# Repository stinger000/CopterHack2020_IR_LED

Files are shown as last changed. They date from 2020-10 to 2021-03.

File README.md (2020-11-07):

# CopterHack2020_IR_LED
The main repository of the team "Atomic Ferrets" in the competition CopterHack 2020

## Описание проекта

- Проект представляет собой систему инфракрасной засечки, которая устанавливается на ворота или любое другое препятствие на трассе, и позволяет фиксировать факт пролёта дроном определенного элемента трассы, а также засекать время пролёта. Данная система позволит максимально автоматизировать проведение любых соревнований, связанных с беспилотным спортом. Так, участнику будет достаточно просто запустить дрон, после чего вылет будет оценен автоматически, в соответствии с заданными критериями. Это позволит исключить возможность судейской ошибки и позволит оценивать проведение любых чемпионатов максимально объективно.

## Каким мы видим результат проекта?

- Проект будет представлен в виде системы инфракрасных датчиков, которые крепятся к препятствиям трассы, а также базовой станции, которая принимает и обрабатывает сигнал с этих датчиков. Датчики могут подключаться последовательно, что позволит устанавливать их на элементы трассы любого размера. В базовых станциях будет реализована возможность их объединения в единую сеть посредствам беспроводного интерфейса, что позволит засекать прохождение любого количества элементов трассы. Также, в рамках проекта будет реализовано приложение для мобильного телефона и ПК, которое будет принимать сигнал с базовых станций, позволит задавать конфигурацию трассы, критерии оценки, и по окончанию вылета выдавать оценку в автоматическом режиме.

## Клевер

- Клевер сейчас является одной из самых популярных платформ для проведения беспилотных соревнований. Разрабатывая нашу систему засечки мы в первую очередь ориентируемся на соревнования с участием этого дрона. Хотя стоит сказать, что использовать устройство можно на любых других соревнованиях. Также ее может использовать любой желающий подготовиться к соревнованиям либо в других личных целях. Конечный вид сборки устройства и установки софта предполагает простоту в использовании

## Место продукта на рынке

- Наша версия системы засечки предполагает, что на дрон не придется ставить дополнительное оборудование, которое будет увеличивать его вес ( максимум - это один светодиод, который позволит определять какой имеено дрон пролетает. Этот вариант еще не реализован ). Многие системы засечек предлагают При этом полный комплект оборудования с реализованным на нём ПО предполагает невысокую стоимость. Конечного продукта нет, поэтому и точной цены тоже, но мы хотим сделать продукт доступным в цене, и опираемся на эту идею при разработке. 

## Стадия разработки
- **Видео** с проверкой работоспособности проекта можете посмотреть по ссылке https://youtu.be/BEOIffvngIY
- Засечка осуществляется за счет фотодиода, реагирующего на свет. Измерения осуществляются путем срабатывания системы на светодиод, закрепленный на противоположной стороне ворот соосно системе срабатывания. 
- Сейчас у нас есть электронная схема, позволяющая снять данные с фотодиода для последующей ее обработки. 
 
- Разработана электронная схема для засечки. 
- Создан алгоритм обработки сигнала с засечки
- Создается софт для ПК с интерфейсом наблюдения замеров времени. https://github.com/stinger000/CopterHack2020_IR_LED_Desktop_GUI
- Была реализована тестовая модель засечки, на которой было проверено срабатывание системы на светодиод, и она оказалась рабочей. 
- Есть система передачи видео с дрона через интернет в любую точку планеты
- Идёт процесс создания мобильного приложения для отслеживания замеров
 
 ### Дальнейшие планы 
- разработать приложение для конечного пользователя на PC и Android
- создать корпус для системы, позволяющий ей правильно работать в полевых условиях (закреплен на препятствие и правильно реагирует на пролет дрона) 

   Возможно рассмотрение некоторых вариантов реализации 
- **Идентификация дронов по частоте мигания светодиода**. Если на квадракоптеры установить по одному светодиоду, и сделать так, чтобы они мигали с индивидуальной для каждого  дрона частотой, то таким образом можно попытаться различить, кто и когда пролетел через препятствие, анализируя полученные сигналы.
- **Идентификация дронов с помощью камер и меток.** В интернете реализован проект система засечки, использующий только камеры самих дронов и передатчики видео. В этом проекте на контрольных точках устанавливается множество aruco-меток, с помощью которых фиксирует время прохождения этих точек. Мы хотим использовать этот проект, таким образом объединив 2 решения. Нашу систему, которая точно определяет время каждого пролета, но пока не может определить кто их соверишл. И систему, которая с неизвестной точностью, но определяет время пролета и id гонщика.

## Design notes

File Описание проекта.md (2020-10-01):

## Описание проекта

- Проект представляет собой систему инфракрасной засечки, которая устанавливается на ворота или любое другое препятствие на трассе, и позволяют фиксировать факт пролёта определенного объекта дроном, а также засекать время пролёта. Данная система позволит максимально автоматизировать проведение любых соревнований, связанных с беспилотным спортом. Так, участнику будет достаточно просто запустить дрон, после чего вылет будет оценен автоматически, в соответствии с заданными критериями. Это позволит исключить возможность судейской ошибки и позволит оценивать проведение любых чемпионатов максимально объективно.

## Каким мы видим результат проекта?

- Проект будет представлен в виде системы инфракрасных датчиков, которые крепятся к препятствиям трассы, а также базовой станции, которая принимает и обрабатывает сигнал с этих датчиков. Датчики могут подключаться последовательно, что позволит устанавливать их на элементы трассы любого размера. В базовых станциях будет реализована возможность их объединения в единую сеть посредствам беспроводного интерфейса, что позволит засекать прохождение любого количества элементов трассы. Также, в рамках проекта будет реализовано приложение для мобильного телефона и ПК, которое будет принимать сигнал с базовых станций, позволит задавать конфигурацию трассы, критерии оценки, и по окончанию вылета выдавать оценку в автоматическом режиме.

## Клевер

- Клевер сейчас является одной из самых популярных платформ для проведения беспилотных соревнований. Таким образом, разрабатывая нашу систему засечки мы в первую очередь ориентируемся на соревнования с участием этого дрона. Хотя стоит сказать, что использовать устройство можно на любых других соревнованиях. Также ее может использовать любой желающий подготовиться к соревнованиям либо в других личных целях. Конечный вид сборки устройства и установки софта предполагает простоту в использовании

## Стадия разработки

- Засечка осуществляется за счет фотодиода, реагирующего на свет. Измерения осуществляются путем срабатывания системы на светодиод, закрепленный на противоположной стороне ворот соосно системе срабатывания. 
- Сейчас у нас есть электронная схема, позволяющая снять данные с фотодиода для последующей ее обработки. 

 - На данный момент 
1) Разработана электронная схема для засечки. 
2) Создан алгоритм обработки сигнала с засечки
3) Создан софт для отслеживания замеров на ПК
4) Была реализована тестовая модель засечки, на которой было проверено срабатывание системы на светодиод, и она оказалась рабочей. 
5) Есть система передачи видео с дрона через интернет в любую точку планеты
6) Идёт процесс создания мобильного приложения для отслеживания замеров
 В дальнейшем планируется : 
 - разработать приложение для конечного пользователя на PC и Android
 - создать корпус для системы, позволяющий ей правильно работать в полевых условиях (закреплен на препятствие и правильно реагирует на пролет дрона)

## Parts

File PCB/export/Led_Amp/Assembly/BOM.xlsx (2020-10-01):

Item # | *Ref Des | *Qty | Manufacturer | *Mfg Part # | Description / Value | *Package | Type | Your Instructions / Notes
1 | U1 | 1 | Analog Devices |  | AD8605ARTZ-R2 | SOT-23-5 | SMD
2 | PH1 | 1 | Betlux Electronics |  | BL-L3522PD | 3mm*5.1mm | thru-hole
3 | R1, R2 | 2 |  |  | RES 2.4M OHM 1/8W 1% 0805 SMD | 0805 | SMD
4 | R3, R4 | 2 |  |  | RES 10k OHM 1/8W 1% 0805 SMD | 0805 | SMD
5 | C1, C2 | 1 |  |  | CAP CER 2.2UF 16V X7R 0805 | 0805 | SMD
Contacts:
bigbani1334@gmail.com
Sergey Stetsky

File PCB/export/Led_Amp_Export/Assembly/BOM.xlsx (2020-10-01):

Item # | *Ref Des | *Qty | Manufacturer | Description / Value | *Package | Type | Your Instructions / Notes
1 | U1 | 1 | Analog Devices | AD8605ARTZ-R2 | SOT-23-5 | SMD
2 | PH1 | 1 | Betlux Electronics | BL-L3522PD | 3mm*5.1mm | thru-hole
3 | R1, R2 | 2 |  | RES 2.4M OHM 1/8W 1% 0805 SMD | 0805 | SMD
4 | R3, R4 | 2 |  | RES 10k OHM 1/8W 1% 0805 SMD | 0805 | SMD
5 | C1, C2 | 2 |  | CAP CER 2.2UF 16V X7R 0805 | 0805 | SMD
6 | JP1, JP2 | 2 | JST | B8B-XH-A |  | thru-hole
Contacts:
bigbani1334@gmail.com
Sergey Stetsky

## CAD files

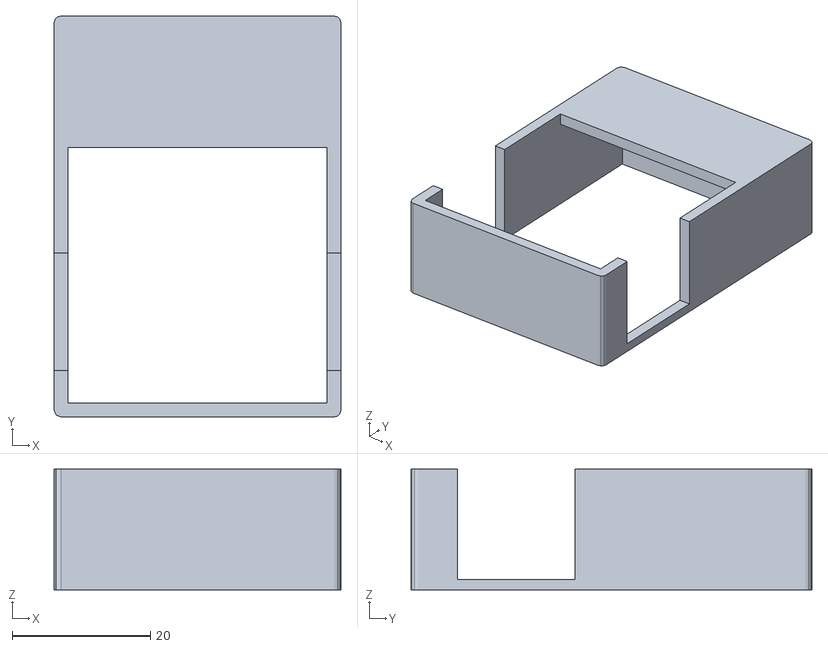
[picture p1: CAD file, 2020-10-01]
models/Body_details/top_cap.stl
41.5 x 58.0 x 17.5

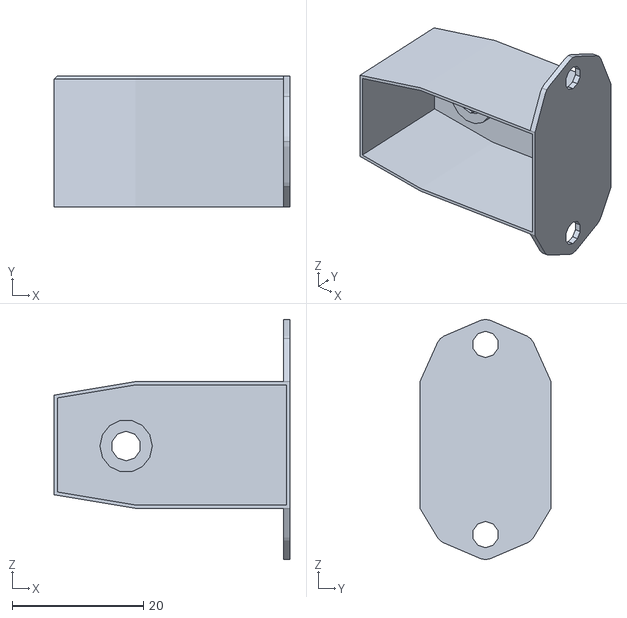
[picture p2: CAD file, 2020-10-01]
models/led_body/креп_свет.stl
36.0 x 20.0 x 36.6

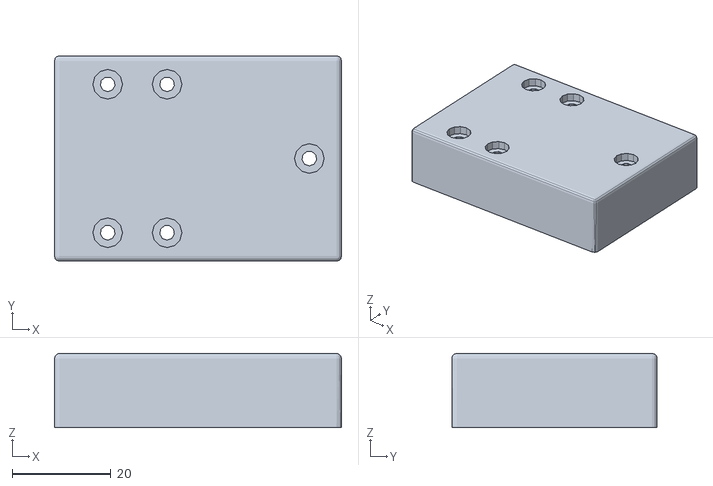
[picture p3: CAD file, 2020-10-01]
models/Body_details/bottom_part.stl
58.0 x 41.5 x 15.0

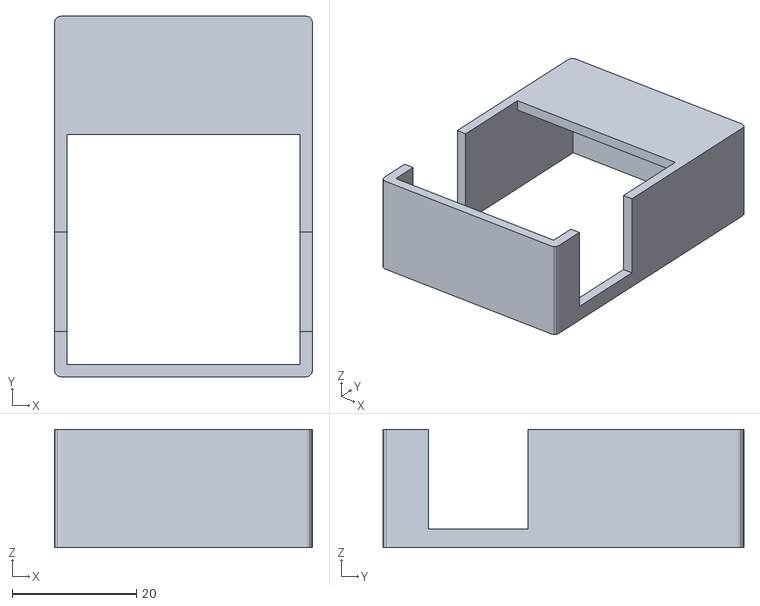
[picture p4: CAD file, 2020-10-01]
models/Body_details/top_part.stl
41.5 x 58.0 x 19.0

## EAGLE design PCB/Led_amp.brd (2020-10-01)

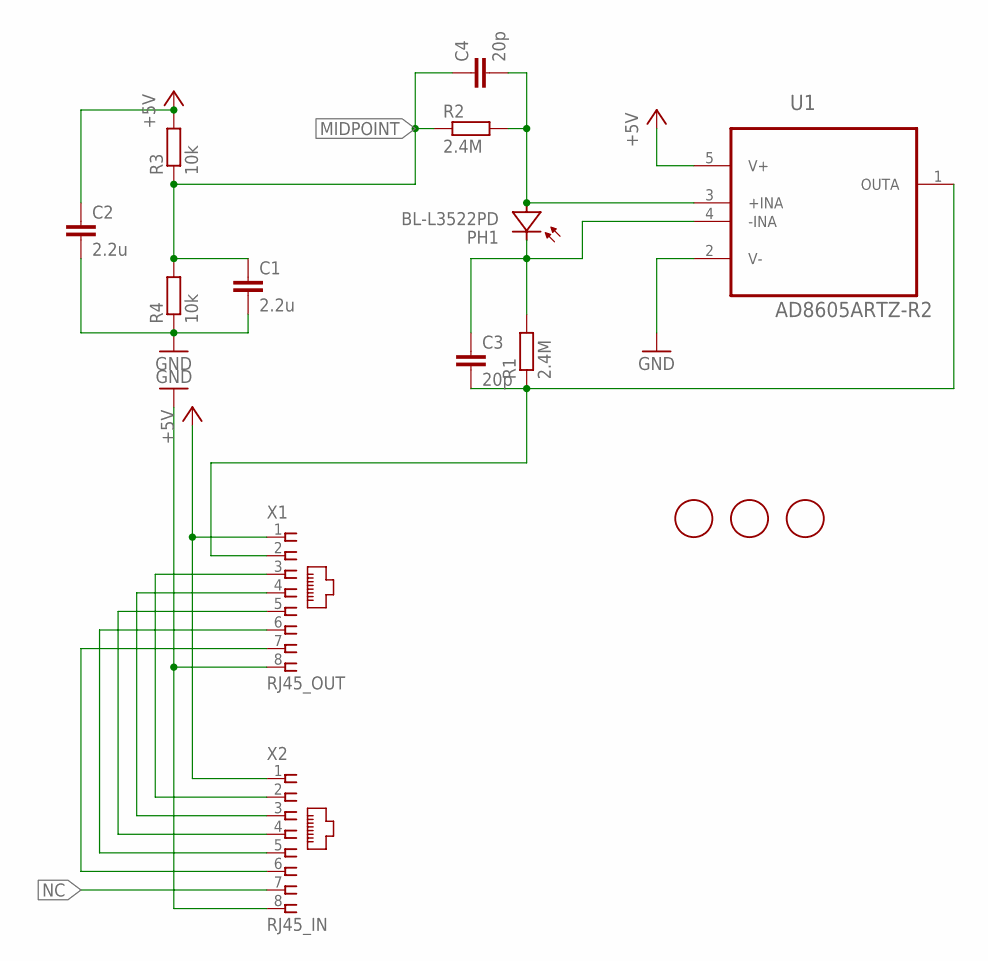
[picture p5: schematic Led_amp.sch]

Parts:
C1, C2: 2.2u; C0805
C3, C4: 20p; C0805
PH1: BL-L3522PD; PDOTODIODE_RECT
R1, R2: 2.4M; R0805
R3, R4: 10k; R0805
U1: AD8605ARTZ-R2; SOT95P290X145-5N
U$1, U$2, U$3: FIDUCIALLARGE_1MM; FIDUCIAL_1MM_LARGE
X1: RJ45_OUT; DS1134
X2: RJ45_IN; DS1134

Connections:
+5V: C2.1, R3.2, U1.5 (V+), X1.1, X2.1
GND: C1.2, C2.2, R4.1, U1.2 (V-), X1.8, X2.8
IN+: C4.2, PH1.A, R2.2, U1.3 (+INA)
IN-: C3.1, PH1.K (C), R1.2, U1.4 (-INA)
MIDPOINT: C1.1, C4.1, R2.1, R3.1, R4.2
NC: X2.7
OUT: C3.2, R1.1, U1.1 (OUTA), X1.2
OUT2: X1.3, X2.2
OUT3: X1.4, X2.3
OUT4: X1.5, X2.4
OUT5: X1.6, X2.5
OUT6: X1.7, X2.6

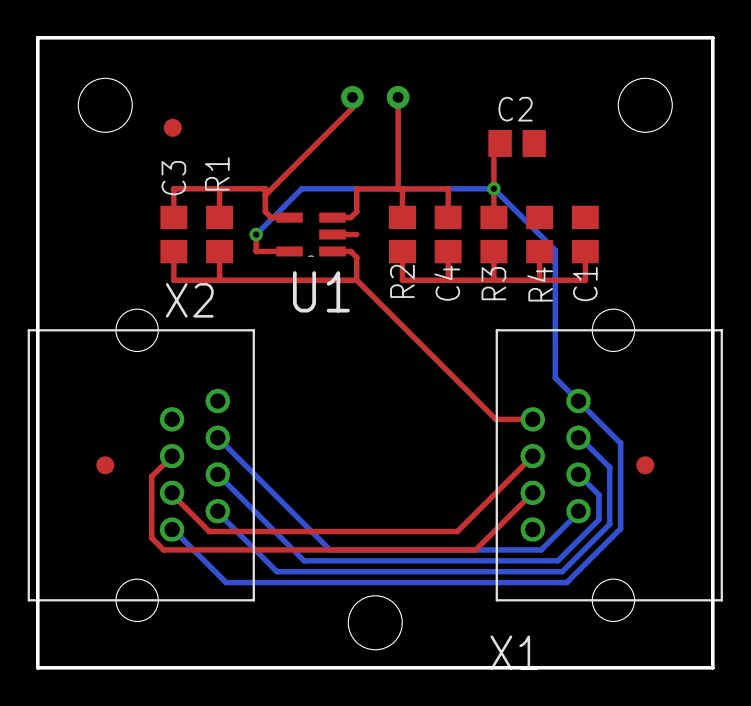
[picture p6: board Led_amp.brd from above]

Board: 2 copper layers, 37.5 x 35.0 mm, 15 parts (1 on the bottom side), 11 nets.

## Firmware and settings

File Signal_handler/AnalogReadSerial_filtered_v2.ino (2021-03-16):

#include <math.h>

const int led_pin=11;
const int sig_pin = A0;

double value = 0.0;
const double gain = 0.25;
double prev = 0.0;
const unsigned long relax_time = 500;
const double treshold = -10;
unsigned long last_time = 0;

const unsigned int interval = 10.;
const unsigned int wait_time = 20;
double Amin = 100000.0;
double Amax = -100000.0;
double tmax, tmin, t_rising, t_falling;
bool rising_edge, falling_edge;
double integral = 0.0;
double d_value;
bool detect = false;

double R = 43.0; // Resistor in low-pass-filter in ligth-emittin diod
double tau = 10.;

double t, t1, t2;
double sensorValue;

const int calib_size = 100; // Calibration time
double noise = 0.0;

const double devider = 0.0033;

double median = 1.;

// the setup routine runs once when you press reset:
void setup() {
    // initialize serial communication at 9600 bits per second:
    Serial.begin(115200);
    Serial.flush();
    //Serial.println("VAL, DET, RIS, FALL"); // for debug 3rd algorith
    //Serial.println("SensVal, Val, SrcSig");
    pinMode(2, OUTPUT);
    pinMode(led_pin, OUTPUT);
  
    //// Calibration
    double calib_arr[2][calib_size];
    double sensorValue;
    double STD_2 = 0.0;
    double mean = 0.0;
    for (int i=0; i<calib_size; i++)
    {
      sensorValue = analogRead(sig_pin)/100.0;
      calib_arr[0][i] = millis();
      delay(interval);
      calib_arr[1][i] = sensorValue;
      mean += sensorValue;
      
      /*
      Serial.print(i);
      Serial.print(" ,");
      Serial.println(sensorValue);
      */
    }
    mean /= (double)calib_size;
    //Serial.print("mean is ");
    //Serial.println(mean);
    for (int i=0; i<calib_size; i++)
    {
      //Accumulate squared deviation from meaт
      STD_2 += (calib_arr[1][i] - mean)*(calib_arr[1][i] - mean);
      //Serial.println(STD_2);
    }
    //Serial.println(STD_2);
    STD_2 /= (double)(calib_size-1);
    //Serial.println(STD_2);
    STD_2 = sqrt(STD_2);
    //Serial.println(STD_2);
    //STD_2 /= (double)sqrt(calib_size);
    noise = STD_2*100.0;
    //Serial.print("The noise size is ");
    //Serial.println(noise);
    //// Noise is STD = sqrt(RMS)
  
    // Calibration are going not so good so decided to set noise manually
    noise = 4;
  
}

void loop() {
    if (Serial.available() > 0){
      char in = Serial.read();
      if (in == 'A') // it's a message sending from python code
        Serial.println(millis());
    }

    //Controliing a IR diod 
    digitalWrite(led_pin, HIGH);
    
    ////// First algorith - use a filter (by Sergei Stetskii)
    /*
    delay(10);
    int sensorValue = analogRead(sig_pin); // Входной сигнал
    double diff = (double)sensorValue - value; // Производная входного сигнала
    value += diff * gain; //Некий аналог low-pass фильтра 
    double overMedian = min(4 * median, diff * diff); //Здесь мы немного ограничиваем входной сигнал, чтобы пики не влияли на среднеквадратичное 
    median = (1 - devider) * median + devider * overMedian;
    double RMS = sqrt(median) * 1.6; //Среднеквадратичное
    
    double overRMS = max(RMS, abs(diff)); 
    double sourceSignal = RMS - overRMS; //Отсекаем весь среднеквадратичный шум
    */
    ////////////////////////////////////////////////
    
    //////// Алгоритм обнаружения пролета
    /*
    if ((diff < treshold) && (millis() >= last_time + relax_time) ){
      last_time = millis();
      //Serial.println("Detected!");
      //Serial.println(diff);
      //Serial.println(millis());
    }
    // debug
    Serial.print(sensorValue);
    Serial.print(" "); 
    Serial.print(value);
    Serial.print(" "); 
    Serial.println(sourceSignal+900);
    
    
    
    //////////////////////////////////////////////////////
      
    ///////////////  Второй алгоритм - по разнице амплитуд
    /*
    sensorValue = analogRead(sig_pin); // Входной сигнал 
    
    t1 = t2;
    t2 = millis();
    t += t2 - t1;
    
    //// equation for low-pass-filter
    d_value = 1/tau * (sensorValue - value)*(t2-t1);
    value += d_value;
    
    if (sensorValue > Amax) {
      Amax = sensorValue;
      tmax = t;
    }
    
    if (sensorValue < Amin) {
      Amin = sensorValue;
      tmin = t;
    }
    */
    //////////////////////////////////////////////////
    
    /*
    if (abs(Amin - Amax) > 3*noise ) {
      Amax = -10000;
      Amin = 10000;
      if ( tmax < tmin )
      {
        rising_edge = true;  
        t_rising = t;
      }
      else if ( tmax > tmin ) 
      {
        falling_edge = true;
        t_falling = t;
      }
      
      if (t_falling>0 & t_rising>0 )
      {
        // Found rising and falling edges
        Serial.print("Detected : time is ");
        Serial.println(t); 
        //Serial.print(", ampitude is ");
        //Serial.println(abs(Amax - Amin));
        Serial.print(", noise is ");
        Serial.println(noise);
        
        delay(10*interval);  
        tmax=0;
        tmin=0;
        t_rising=0;
        t_falling=0;
      }
    }
    */

    //////////////////////// Третий алгоритм - имитация обычного low-pass фильтра
    
    sensorValue = analogRead(sig_pin); // Входной сигнал 
    
    t1 = t2;
    t2 = millis();
    t += t2 - t1;
      
    //// equation for low-pass-filter
    d_value = 1/tau * (sensorValue - value)*(t2-t1);
    value += d_value;
    
    //delay(interval);

    //debug in plotter
    //Serial.print(sensorValue);
    //Serial.print(" ");
    //Serial.println(value);
    //Serial.print(" ");
    //Serial.print(detect*100);
    //Serial.print(" ");
    //Serial.print(rising_edge*200);
    //Serial.print(" ");
    //Serial.println(falling_edge*300);
    detect = false;
    
    /////// Обработка сигнала
    
    
    if (value > Amax & t>3000) {
      Amax = value; 
      tmax = t;
    }
    if (value < Amin & t>3000) {
      Amin = value; 
      tmin = t;
    }
    
    //////////////////////////////////////////
    
    
    //Serial.print(Amax);
    //Serial.print(" ");
    //Serial.println(Amin);
    //Serial.println(t);
    //Serial.println(tmin);
    //Serial.println(tmax);
    
    
    
    if (abs(Amax - Amin) > 3*noise ) {
      if (falling_edge)
      {
        if ( tmax > tmin ) {
          rising_edge  = true;
        }
      }  
      else if ( tmax < tmin )
      {
        falling_edge = true;
      }

      tmax = 0.0;
      tmin = 0.0;
      if ( rising_edge & falling_edge  )
      {
        // Found rising and falling edges
        
        //Serial.print("Detected : time is ");
        //Serial.println(t); 
        //Serial.print(", ampitude is ");
        //Serial.println(abs(Amax - Amin));
        //Serial.print(", noise is ");
        //Serial.println(noise);
        
        detect = true;
        // Send time by serial port to GUI
        Serial.println(millis());
        delay(1000); // for example  
        t2= millis();
        tmax=0.0;
        tmin=0.0;
        rising_edge = false;
        falling_edge = false;
      }
      Amax = -10000;
      Amin = 10000;
    
    }
    
    /////////////////////////////////////////////
    
    /////////////////////////////////////////////

    /////////////// Строки для дебага ///////////
    
    //Serial.println(sensorValue);
    //Serial.println(diff);
    //Serial.print(int(100*diff));
    //Serial.print(", ");
    //Serial.println(value);
    //Serial.print(", ");
    //Serial.println(sourceSignal * (diff / abs(diff)));  // Немного дебага
    //Serial.println(sourceSignal);
}

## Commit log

2020-10-01 add 3d-models
    [bottom_part.stl, top_cap.stl, top_part.stl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]
2020-10-01 Add schematic and PCB
    [BOM.xlsx, Led_amp.brd, Led_amp.sch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]
